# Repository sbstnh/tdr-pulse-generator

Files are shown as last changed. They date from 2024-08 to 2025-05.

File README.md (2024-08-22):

# TDR pulse generator

This repository contains the PCB design files (KiCAD 8) of a simple TDR pulse generator.

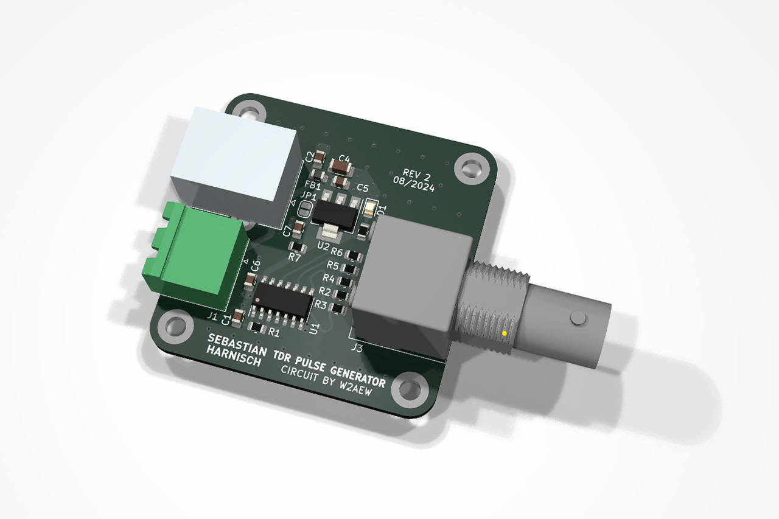
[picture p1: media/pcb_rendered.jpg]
TDR pulse generator PCB rendering


## Introduction

Almost a decade ago W2AEW posted a video on his YouTube channel showing a cheap and easy to build pulse generator for time domain reflectometry (TDR), consisting of only a simple hex inverter with schmitt-trigger inputs 74AC14 and a few passive components.
The schematic looks something like this:

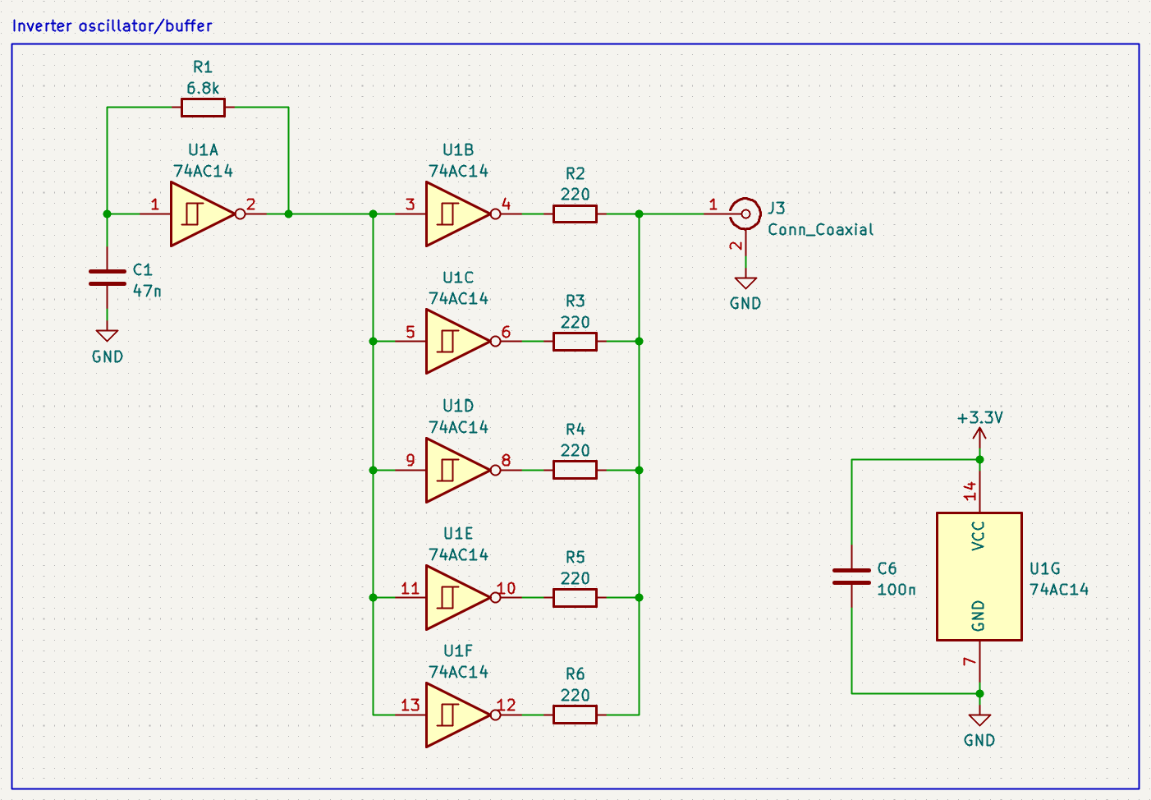
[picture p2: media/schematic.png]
Schematic


It consists of a schmitt-trigger oscillator and a few inverters used as a driver with a (somewhat) fast rise time.

This repository contains an implementation of such a circuit.

## Results

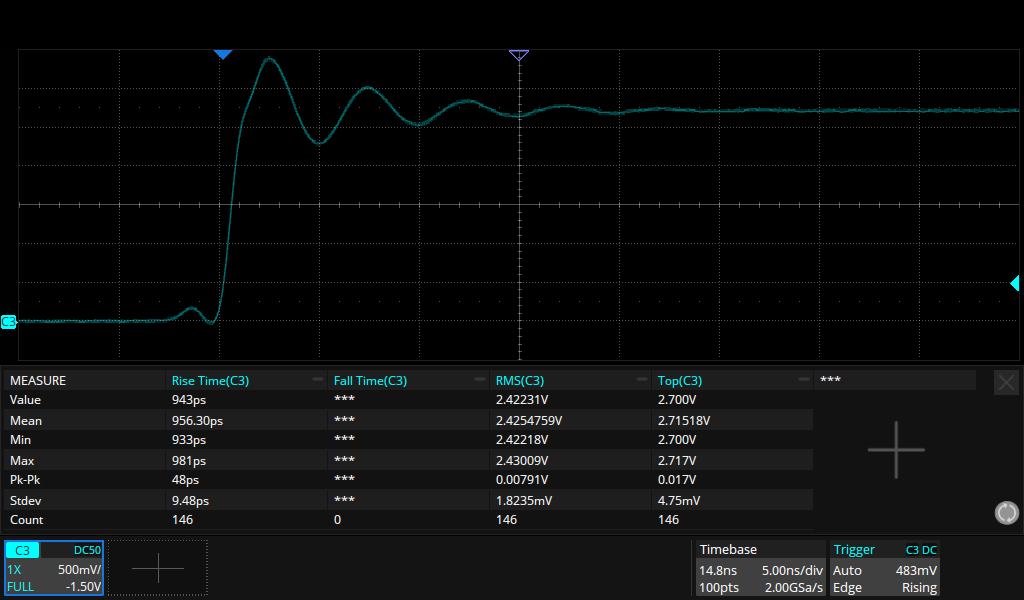
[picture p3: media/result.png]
Screenshot of the rising edge


For the test I used my Siglent SDS2000X Plus scope (500MHz, 800ps rise time typical @ 50 Ohm) which has to stretch its legs for this one: I measured a respectable rise time of about 960ps.
In his video, W2AEW measured something like 2ns of rise time for his circuit using DIP packaged hex inverter. Both his and my variant show a noticable ringing.

## Credits

Circuit presented by W2AEW on his youtube channel. The video can be found here: [https://www.youtube.com/watch?v=9cP6w2odGUc](https://www.youtube.com/watch?v=9cP6w2odGUc).

## Further information

More details are available on my personal site [https://sebastianharnisch.de](https://sebastianharnisch.de).

## Disclaimer

This repository all its Content is provided "AS IS" without any warranty whatsoever.

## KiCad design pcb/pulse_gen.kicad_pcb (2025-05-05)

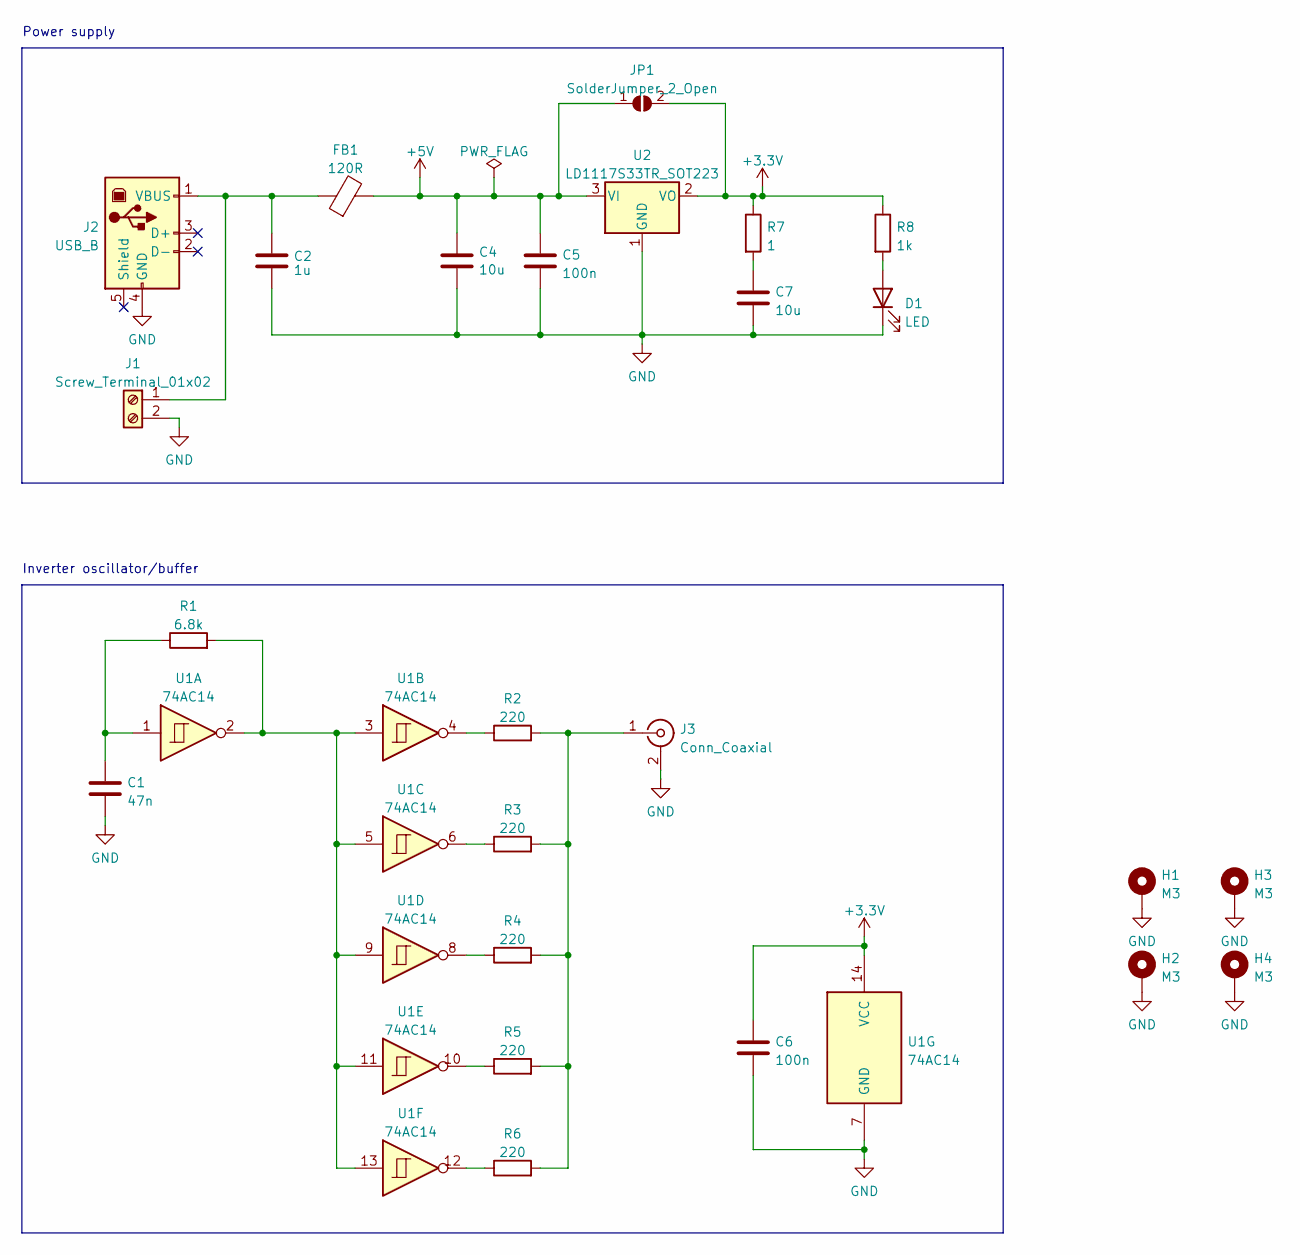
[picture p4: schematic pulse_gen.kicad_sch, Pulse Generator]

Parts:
C1: 47n; C_0805_2012Metric
C2: 1u; C_0805_2012Metric
C4: 10u; C_1206_3216Metric
C5, C6: 100n; C_0805_2012Metric
C7: 10u; C_0805_2012Metric
D1: LED; LED_0805_2012Metric
FB1: 120R; L_0805_2012Metric
H1, H2, H3, H4: M3; MountingHole_3.2mm_M3_DIN965_Pad
J1: Screw_Terminal_01x02; PhoenixContact_MSTBA_2,5_2-G_1x02_P5.00mm_Horizontal
J2: USB_B; USB_B_Lumberg_2411_02_Horizontal
J3: Conn_Coaxial; BNC_Amphenol_B6252HB-NPP3G-50_Horizontal
JP1: SolderJumper_2_Open; SolderJumper-2_P1.3mm_Open_RoundedPad1.0x1.5mm
R1: 6.8k; R_0805_2012Metric
R2, R3, R4, R5, R6: 220; R_0805_2012Metric
R7: 1; R_0805_2012Metric
R8: 1k; R_0805_2012Metric
U1: 74AC14; SOIC-14_3.9x8.7mm_P1.27mm
U2: LD1117S33TR_SOT223; SOT-223-3_TabPin2

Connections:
+3.3V: C6.1, JP1.2 (B), R7.1, R8.1, U1.14 (VCC), U2.2 (VO)
+5V: C4.1, C5.1, FB1.2, JP1.1 (A), U2.3 (VI)
GND: C1.2, C2.2, C4.2, C5.2, C6.2, C7.2, D1.1 (K), H1.1, H2.1, H3.1, H4.1, J1.2, J2.4 (GND), J3.2 (Ext), U1.7 (GND), U2.1 (GND)
unnamed: C1.1, R1.1, U1.1
unnamed: C7.1, R7.2
unnamed: D1.2 (A), R8.2
unnamed: C2.1, FB1.1, J1.1, J2.1 (VBUS)
unnamed: J3.1 (In), R2.2, R3.2, R4.2, R5.2, R6.2
unnamed: R1.2, U1.2, U1.3, U1.5, U1.9, U1.11, U1.13
unnamed: R2.1, U1.4
unnamed: R3.1, U1.6
unnamed: R4.1, U1.8
unnamed: R5.1, U1.10
unnamed: R6.1, U1.12

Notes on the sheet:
Power supply
Inverter oscillator/buffer

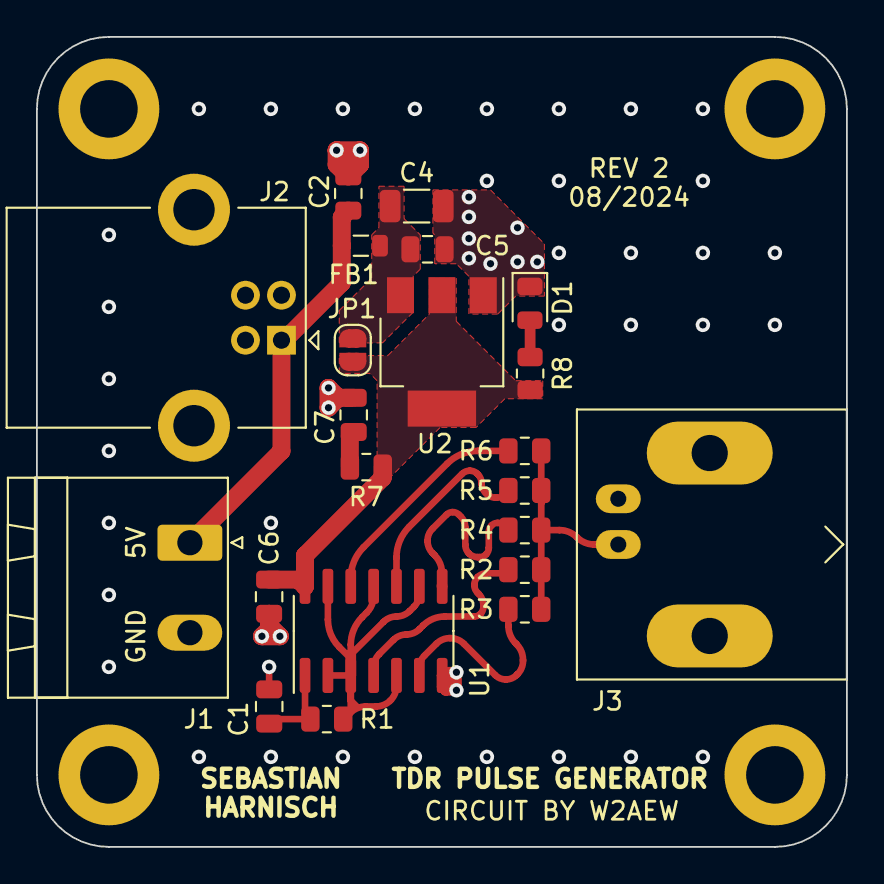
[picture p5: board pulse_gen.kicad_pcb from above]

Board: 4 copper layers, 45.0 x 45.0 mm, 26 parts (0 on the bottom side), 14 nets.
